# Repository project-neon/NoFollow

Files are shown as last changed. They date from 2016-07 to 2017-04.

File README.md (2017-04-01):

# NoFollow
The Software of NoBox's Line Follow robot of 2016
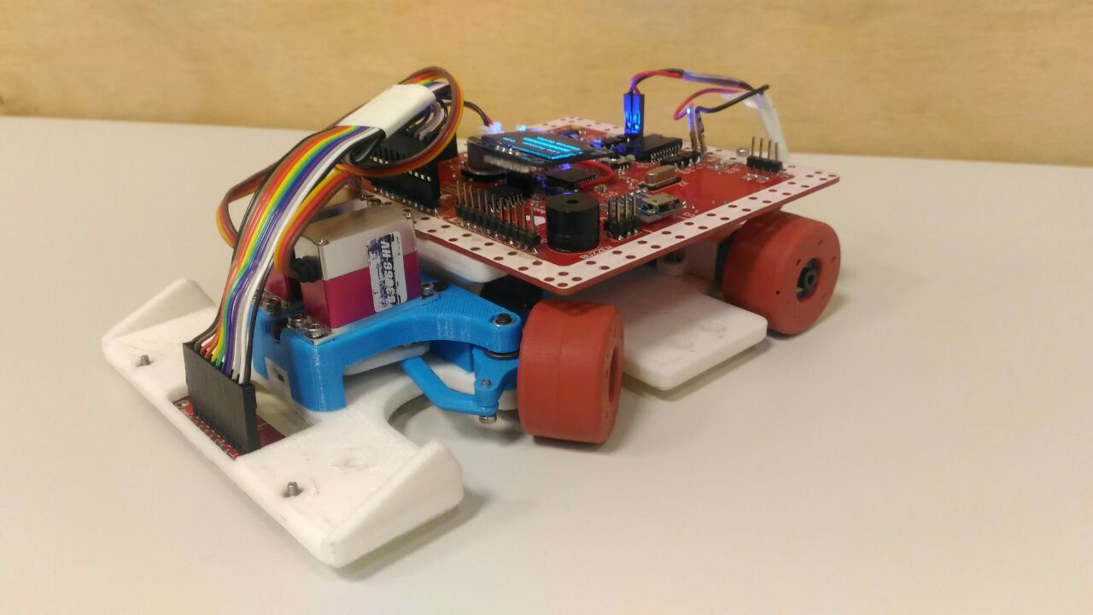
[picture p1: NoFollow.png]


<p align="center";> <b>NoFollow Final Version</b> </p>

# Parts of the puzzle

* `Firmware`: Is the main firmware that controls all the functions of the robot.
* `Eletric`: This keeps all the information about the electronics for the line following robot ‘NoFollow’.
* `Mechanic`: Contains the STL files of the robot design.

# Parts of the `Firmware` puzzle

* `activities`: Controls the robots motor power, threads callbacks and PID constants.

* `interface`: Show in the LED interface the time to stop the robot and read the comands by a joystick.

* `lineReader`: Read the outside sensors and check the conditions.

* `motors`: Initiates the "pinMODEs", sets power and directions of the motors.

* `pid`: Configures PID control on the angular
velocity of the robot.

* `robot`: Configurates the correct pinMODEs and beeps, defines the current robot's state.

* `runner`: Is the "menu" of the robot. In the interface receive the comands by the joystick to do tests actuators, calibrate steering and follow line.

# Contributors
* [Gustavo Silva de Paula](https://github.com/Gustavo-dPaula)
* [Ivan Seidel](http://github.com/ivanseidel)
* [João Pedro Poloni Ponce](https://github.com/JoaoPedroPP)
* [Lucas Andrade Cioffi](https://github.com/lacioffi)
* [Marcelo Farias](https://github.com/MarceloFariaz)
* [Yves-Medhard Tibe-Bi](https://github.com/yvesmedhard)

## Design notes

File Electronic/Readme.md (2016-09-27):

# NoFollow - Electronics



## CircuitMakerProject link <a href="https://workspace.circuitmaker.com/Projects/Details/Marcelo-Farias/NoFollowBoard">here</a>

## General Stuff

This repository keeps all the information about the electronics for the line following robot ‘NoFollow’.

THE MOST IMPORTANT ADVICE YOU CAN EVER GET ABOUT USING CIRCUITMAKER IS:
DONT. TRUST. DATABASE. COMPONENTS.

We did. It was not good.
Many of them are wrong - be it wrong sizes, wrong pins in the wrong places, wrong names, whatever! Don’t EVER 
trust them! Never! If possible, make them yourself! We had TONS of troubles because of this!

Anyway, proceeding:

To control the robot, we chose the Atmega 32U4 microcontroler (the same one that arduino Leonardo uses). 

However, this choice proved inadequate, since it’s memory was too small and couldn’t fit the entire intended 

program. We had to scrap the IMU because it’s library was too heavy and the LCD library had to suffer some
modifications to fit.

Here are the project sheets:

## Project Sheets

### `Main Sheet`:

Main Sheet

  This sheet just links all the other sheets together. The idea is that the 'Core' part does all the processing while
the other sheets worry about interfacing or power-related stuff.

### `Core Sheet`: 

Core Sheet

  In the core sheet we have the microcontroller and the necessary components to make it work properly - like a 
crystal oscillator and some capacitors. It also contains the usb header and its basic circuit.
The reset button is also included.

### `Power Sheet`:

Power Sheet

  This is the power sheet, and is filled with (duh) power related stuff.
This robot was designed to work with a battery of 7.4V which was connected to a voltage regulator LM1117 to 
supply 5V continuous. It has a contact to keep the circuit safe when turning on and off.

### `Sensor Sheet`:

Sensor Sheet

  We tried to put all the input/output devices in this sheet.
To detect the line on the ground we chose two analog arrays of eight infrared sensors, one overlapping the
other. Since the ATmega32U4 doesn't have 16 analog I/O’s, we had to use a mutiplex to access all 16 inputs
through only one pin.
  However, due in part to the small size of the Atmega’s memory and due in part to last-minute assembly, we only 
used one sensor. The robot worked anyway, but we don’t know if it would have worked better with two of them.
  Note about the MUX: we incorrectly used a big package, but there are smaller ones (and easier to find!) if you 
want to. We would have used them, but again: don’t trust database components.
  The capacitors are necessary for filtering the IMU (whatever that means).
  The LED_ON gate is connected directly to the ATMEGA, so as to turn off the LEDs when not in use and preserve 
battery. In hindsight, this was mostly useless.
  The buzzer was never used due to the memory shortage problem already cited.
  The button worked okay like this BUT it was placed wrongly on the circuit board. It was placed in a 45º angle, 
but the button works with a 90º axis so, for example, UP became UP-RIGHT and LEFT became UP-LEFT, and so forth. 
Like a compass turned 45 degrees to the right, you get it?

### `Comunications Sheet`:

Comunications Sheet

  This sheet was supposed to be for all communications - which eventually turned out to be just a bluetooth 
module.
  HC05 is a simple bluetooth module that worked fine. The small circuit on its left is a thingy that steps the 
voltage up and down so the HC05 doesn’t burn the Atmega and vice-versa. It’s very important.

### `Motor Sheet`:
Motor Sheet

  This is the sheet where all motors and things-that-go-spinning went.
There is an H-bridge for motor control, complete with all the stuff it needs to work, and the motors all have 
diodes to prevent dangerous reverse currents. 
  There are also LED’s that indicate if the motor is going forwards or backwards. These were just for debugging, 
so they aren’t necessary, but they honestly look pretty cool. I recommend them.
IMPORTANT: while routing, we used small copper lines to connect the motors to the H-bridge. We later fixed it, 
which was very good, because or else we would have the first ever line-burning robot.
  However, the H-bridge has a big metal plate underneath it to use as ground/heatsink. So don’t repeat our
mistake and don’t put routes underneath the H-bridge. We had to cut out some isolant tape and glue it on the 
H-bridge, which worked, but you can do better than that.

## Routed Board
Routed Board

This is the final routed board. Notice the huge ground lines - these are important, since the motors are going 
to draw a LOT of current. 
  IMPORTANT: the LCD display is routed incorrectly. This was a CircuitMaker bug which (apparently) didn’t save a 
fix we made to the LCD part and ended up carrying a wrongly-pinned LCD to the routing process and, basically, 
gave us trouble.

## About soldering:
Please, PLEASE check if your PCB manufacturing company can make metallized vias. To our surprise, ours didn’t, 
which meant we had to solder 200+ metal bits to make them work, and it was generally unpleasant and caused us a 
lot of headache.

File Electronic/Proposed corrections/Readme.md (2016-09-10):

# Proposed corrections

This folder contains the (semi)fixed project.
We fixed the errors on CircuitMaker and exported the project again.
This was partly educational and partly so you can use it without the headaches we had.
Let's get on to it:

##WHAT WAS FIXED:

###MUX size:
The MUX was inverted and the package used was unecesseraly big. This was fixed.

###LCD pins:
LCD pins were not properly connected. Now they are.

###ATMEGA pins:
MC pins were reallocated to simplify stuff and make stuff prettier and stuff.
New positions are available in the sheet.

###Button:
Button was rotated because it was wrong before.

###L298 Ground:
Now the L298 is properly grounded. Heat dissipation is better this way.

###Servos:
Servos are now connected directly to the battery. That's how they were supposed to be.

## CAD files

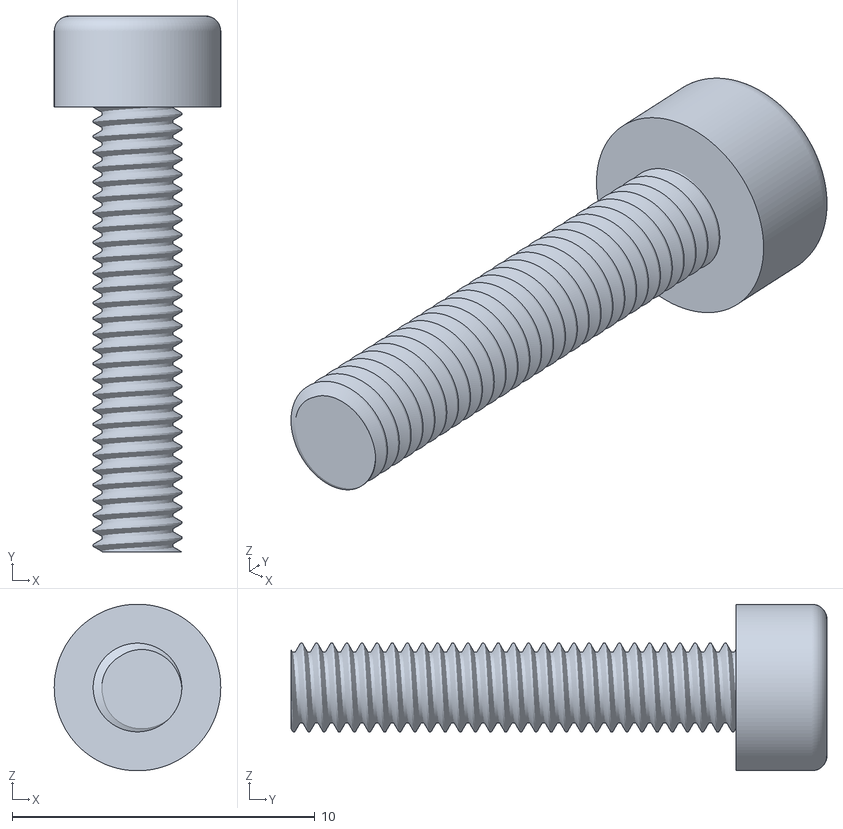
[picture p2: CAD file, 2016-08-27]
Mechanics/STLFiles/Allen_M3x18.stl
5.50 x 17.7 x 5.50

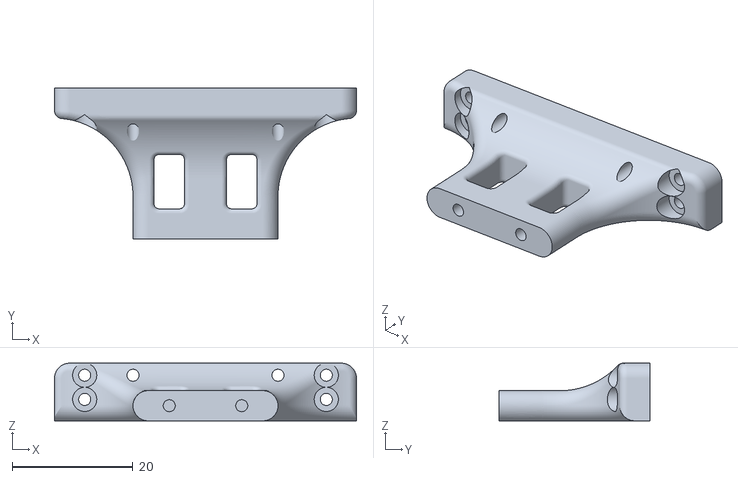
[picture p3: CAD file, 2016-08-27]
Mechanics/STLFiles/Support_Board.stl
50.0 x 25.0 x 9.55

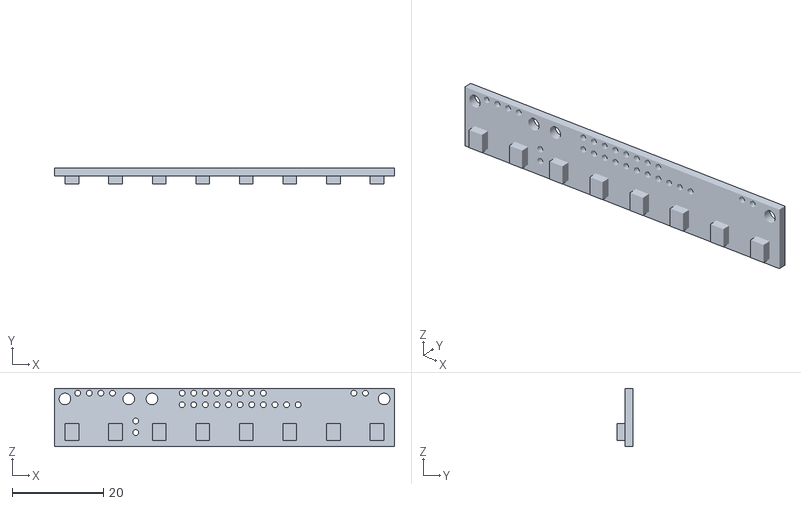
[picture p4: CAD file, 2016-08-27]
Mechanics/STLFiles/QTR-8RC.stl
74.4 x 3.48 x 12.7

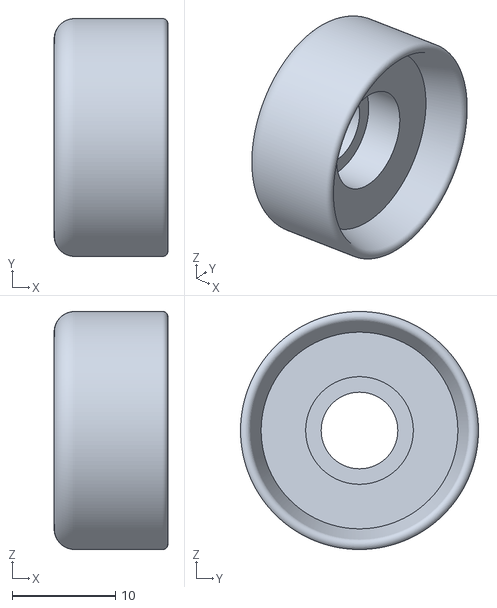
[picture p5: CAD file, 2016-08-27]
Mechanics/STLFiles/Wheel.stl
11.0 x 23.0 x 23.0

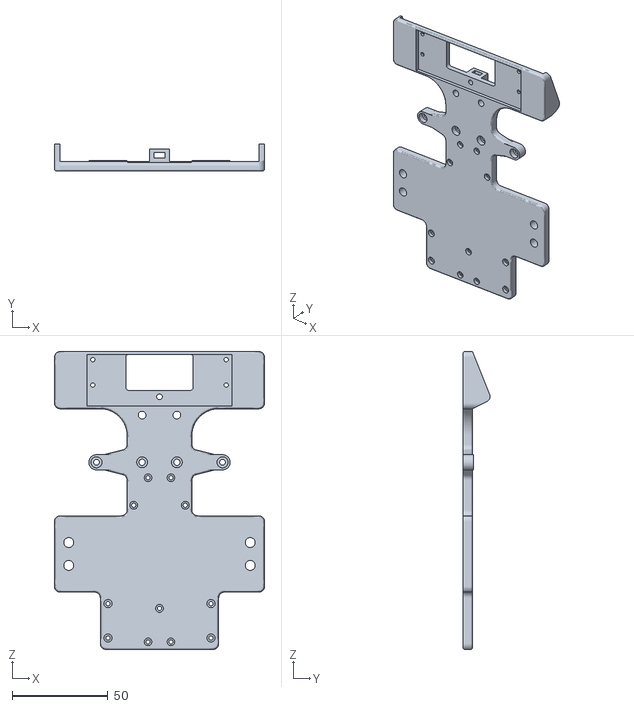
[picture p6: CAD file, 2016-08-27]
Mechanics/STLFiles/Base.stl
110.0 x 14.2 x 156.0

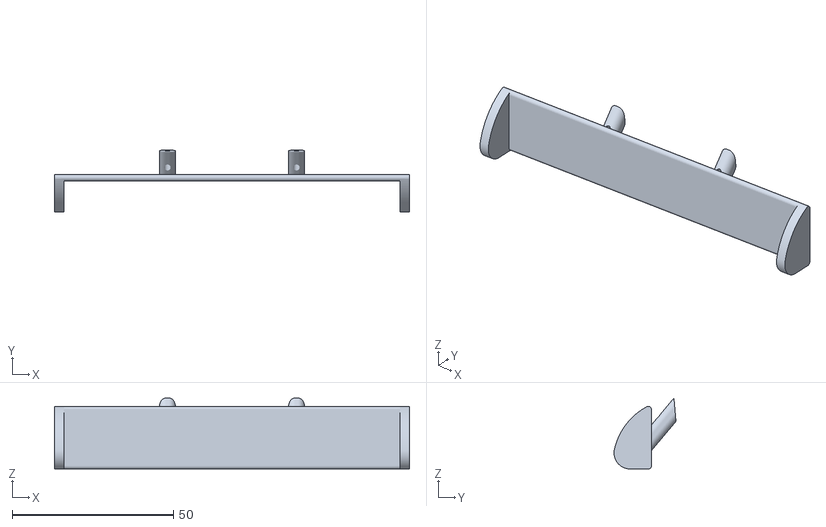
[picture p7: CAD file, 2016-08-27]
Mechanics/STLFiles/Spoiler.stl
110.0 x 19.2 x 22.0

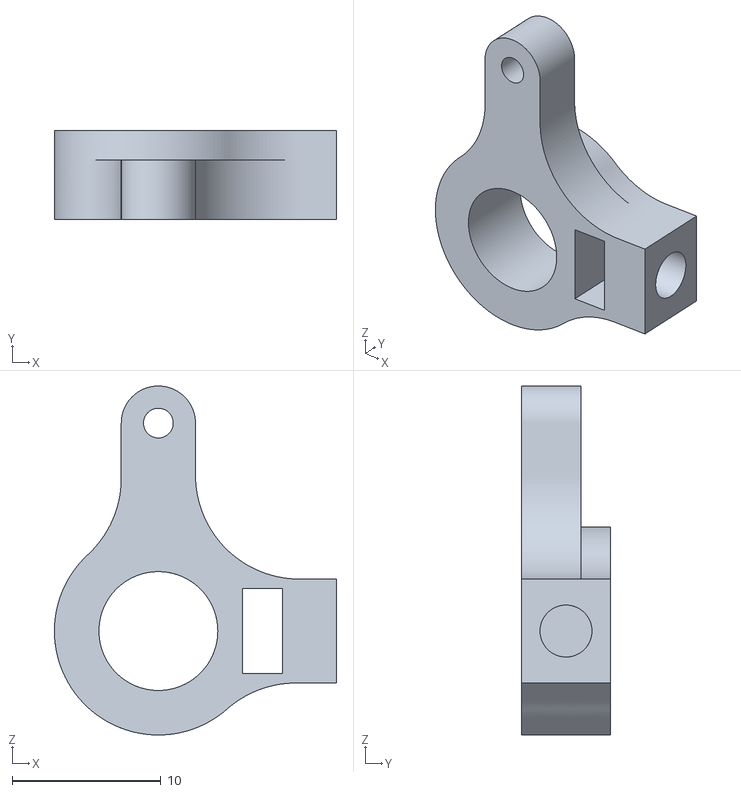
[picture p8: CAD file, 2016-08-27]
Mechanics/STLFiles/Direction_Bearing_Ring_Left.stl
19.0 x 6.00 x 23.5

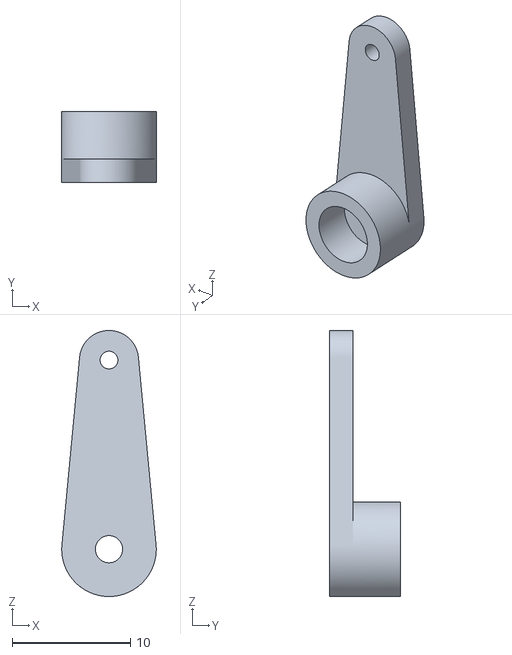
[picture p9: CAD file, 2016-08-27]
Mechanics/STLFiles/Servo_Arm.stl
8.00 x 6.00 x 22.5

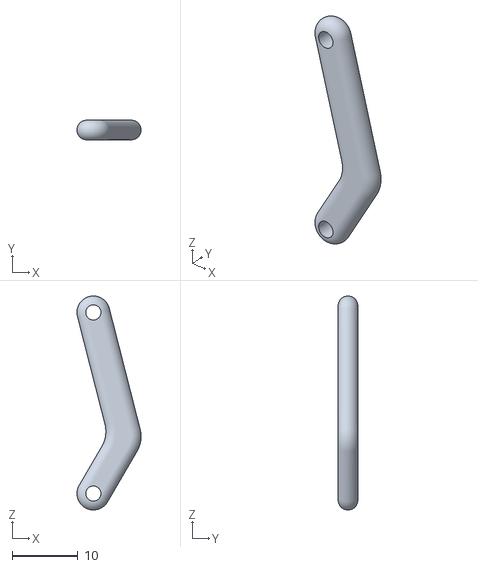
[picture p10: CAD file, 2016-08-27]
Mechanics/STLFiles/Direction_Bar_Right.stl
9.74 x 3.00 x 32.5

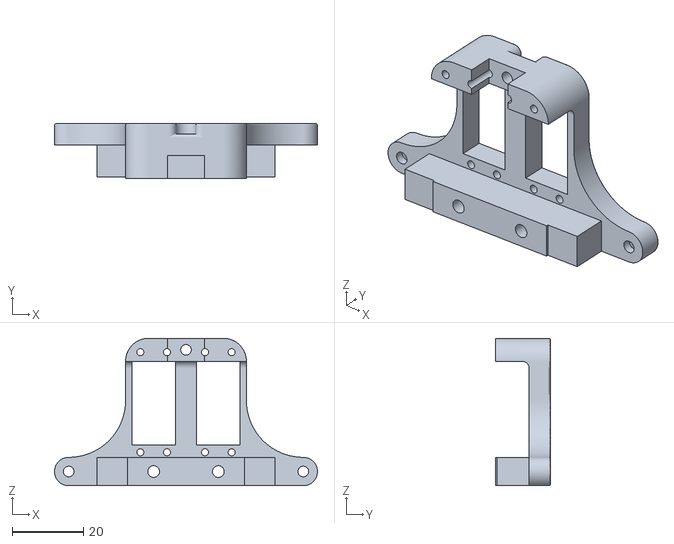
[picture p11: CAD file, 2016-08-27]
Mechanics/STLFiles/Fixer_Direction.stl
74.0 x 15.5 x 41.5

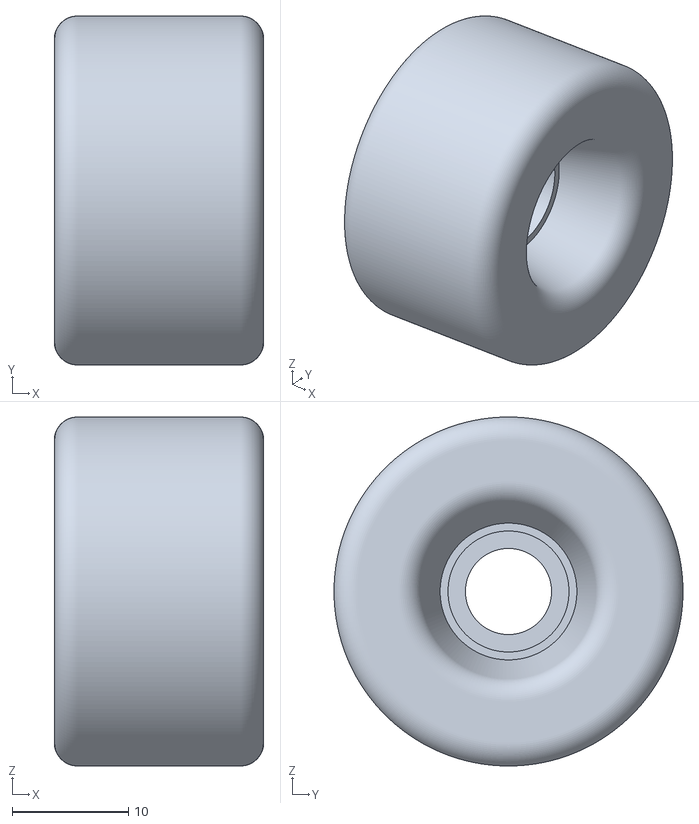
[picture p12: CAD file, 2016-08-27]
Mechanics/STLFiles/Wheel_With_Tire.stl
18.0 x 30.0 x 30.0

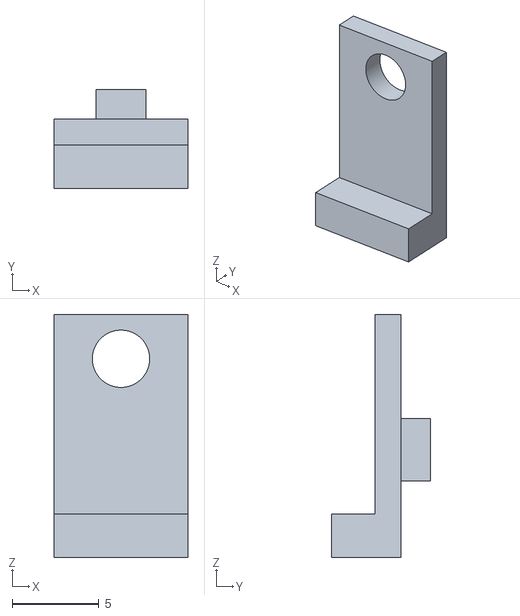
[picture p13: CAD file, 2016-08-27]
Mechanics/STLFiles/QTR-1A.stl
7.70 x 5.70 x 14.0

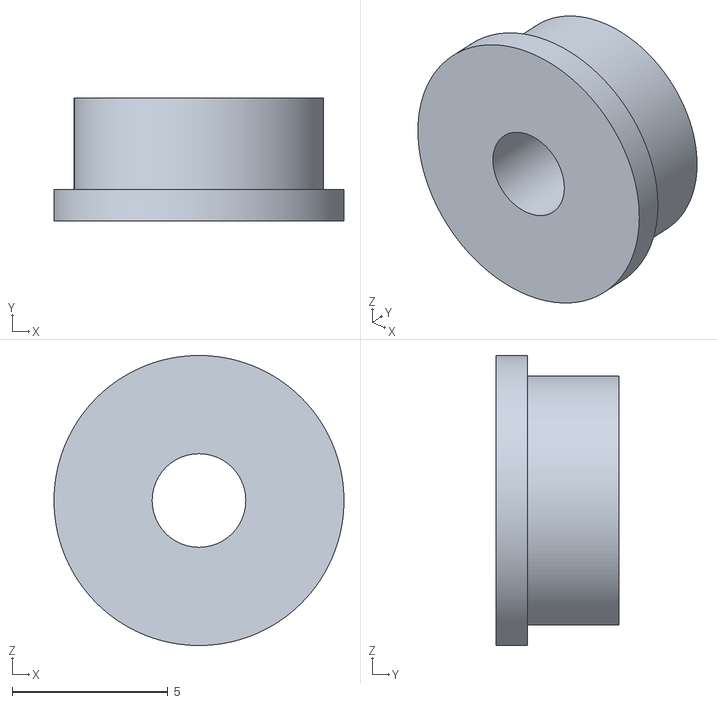
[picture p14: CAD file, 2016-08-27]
Mechanics/STLFiles/Bearing_3x3x8 .stl
9.30 x 3.94 x 9.30

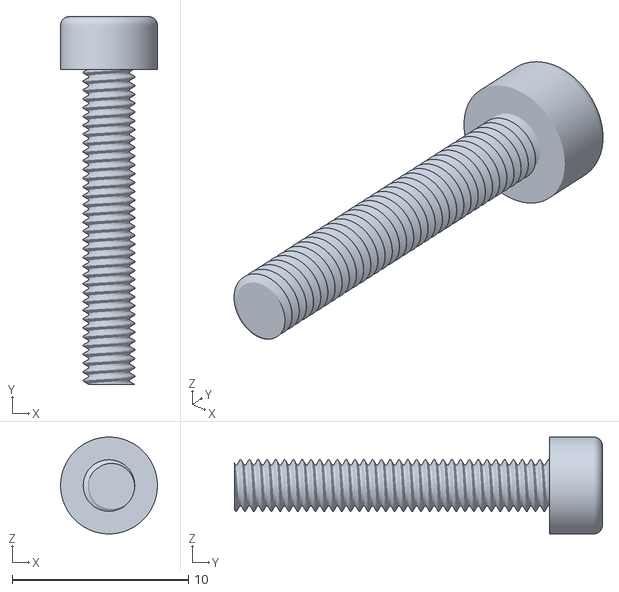
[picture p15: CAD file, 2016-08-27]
Mechanics/STLFiles/Allen_M3x21.stl
5.50 x 20.9 x 5.50

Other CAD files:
Mechanics/STLFiles/Direction_Bearing_Ring_Right.stl
Mechanics/STLFiles/Battery_Support.stl
Mechanics/STLFiles/Sensor_Arm.stl
Mechanics/STLFiles/Direction_Bar_Left.stl
Mechanics/STLFiles/Allen_M2x10.stl
Mechanics/STLFiles/Allen_M3x10.stl
Mechanics/STLFiles/Micro_Gear_Motor_Extended_30-1_With_Bracket.stl
Mechanics/STLFiles/Nut_M2x1.5x4.stl
Mechanics/STLFiles/Nut_M3x4x5.5 (Autolock).stl
Mechanics/STLFiles/Nut_M3x4x5.5.stl
Mechanics/STLFiles/Rear_Wheel_Cube.stl
Mechanics/STLFiles/ServoTGY-306GV2.2.stl
Mechanics/STLFiles/Washer_7x3.3x0.5.stl
Mechanics/STLFiles/Zippy_Lipo_1300mAh.stl

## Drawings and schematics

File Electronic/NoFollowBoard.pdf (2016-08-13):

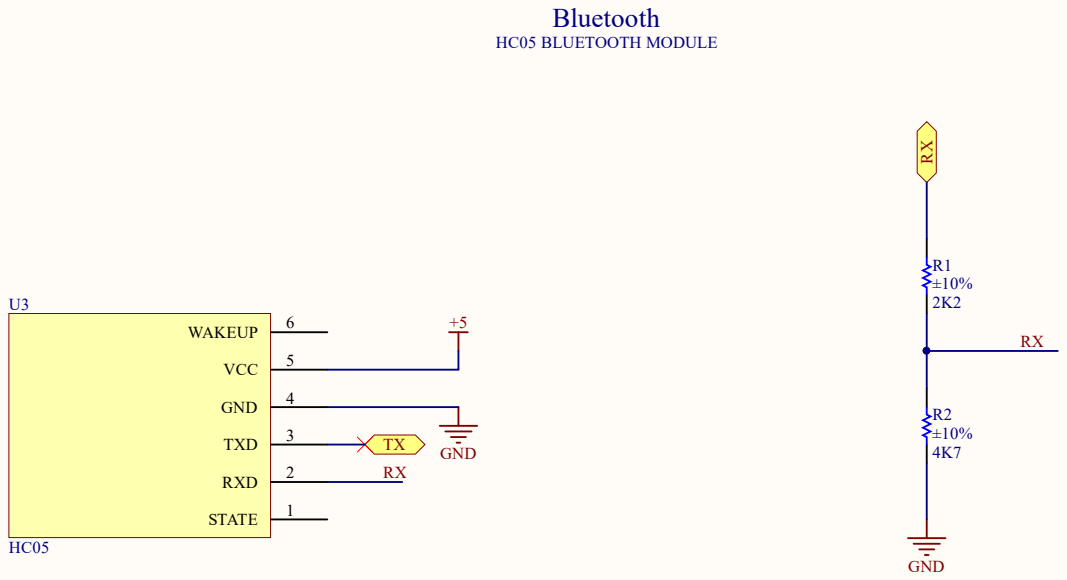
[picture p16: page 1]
5 BLUETOOTH MODULE

Size A | Nu m ber | Revisio n

Date: 1/0 7/2 6 | Sheet o f
File: C o m m u nicatio n.SchDo c | Drawn B y :

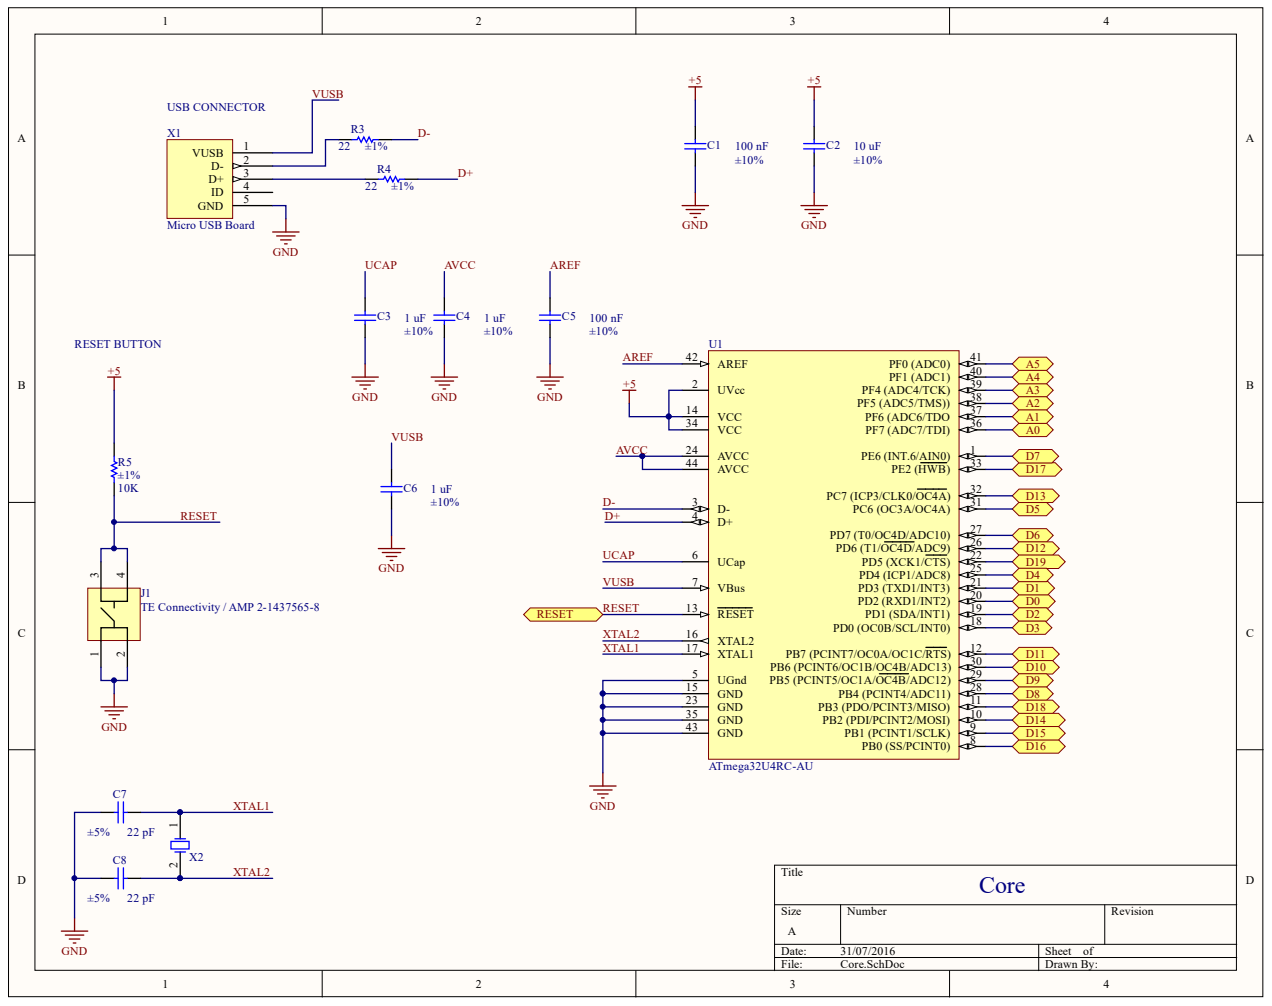
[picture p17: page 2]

1 4

1 5
2 3

Size | Nu m ber | Revisio n

Date: 1/0 7/2 6 | Sheet o f
File: C o re.SchDo c | Drawn B y :

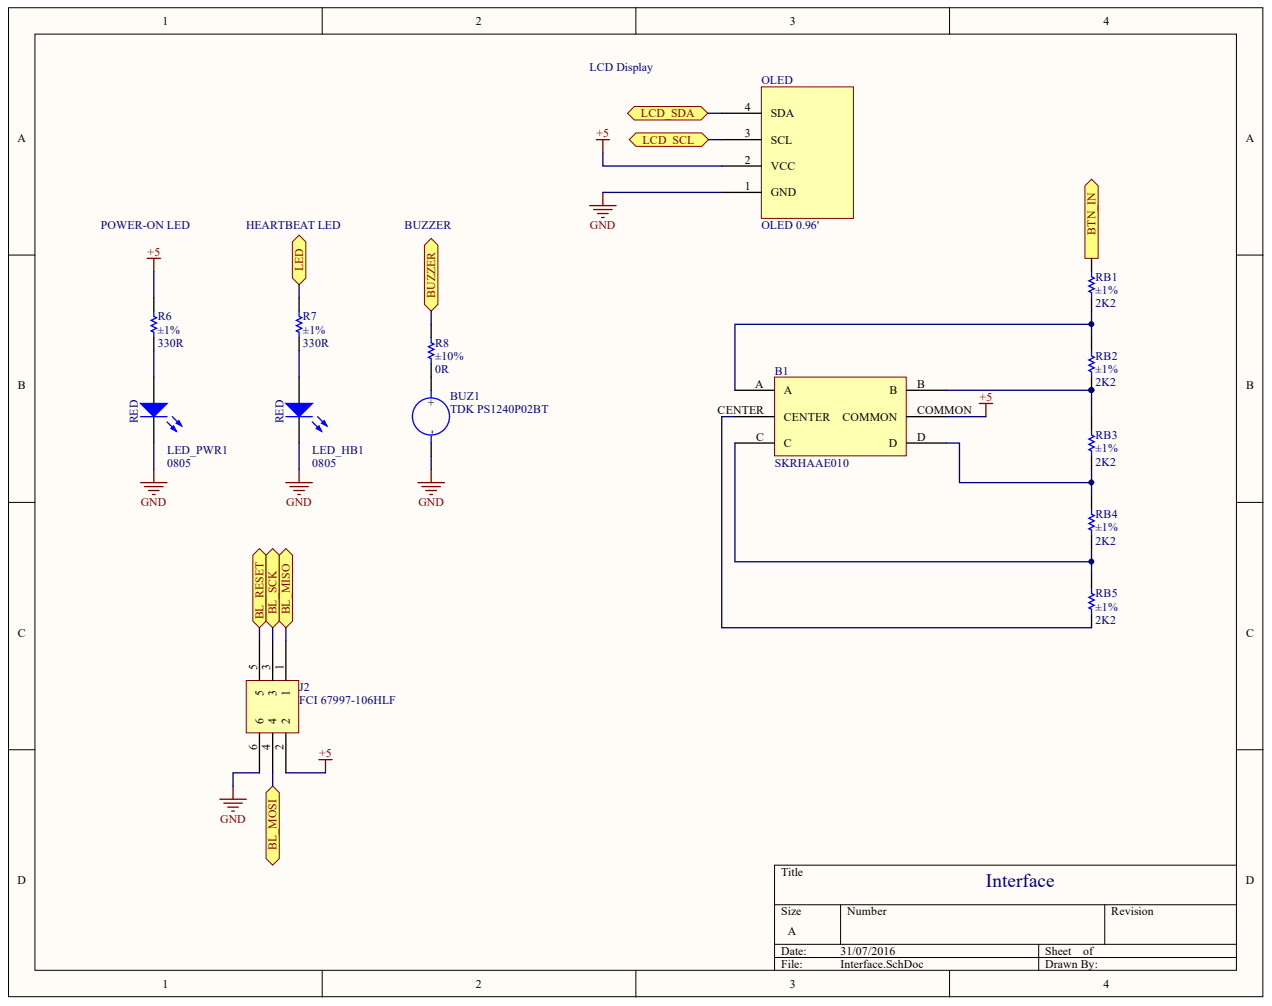
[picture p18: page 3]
GND; GND LED; BUZZER; LCD Display; -ON LED; HEARTBEAT LED; OLED 0.9; TDK PS1

Size | Nu m ber | Revisio n

Date: 1/0 7/2 6 | Sheet o f
File: I nter face.SchDo c | Drawn B y :

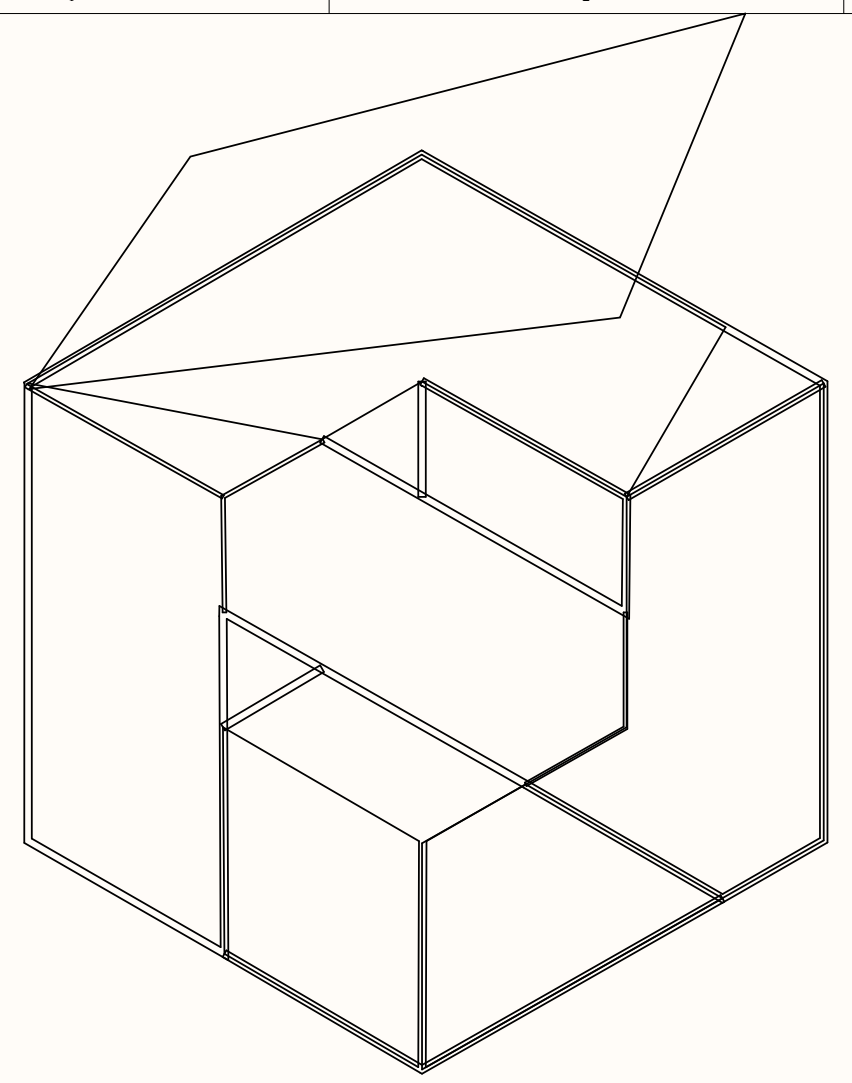
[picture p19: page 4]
Date:; Sheet of; File:; Logo-Linhas-Placa Circuito.SchDoc; Drawn By:

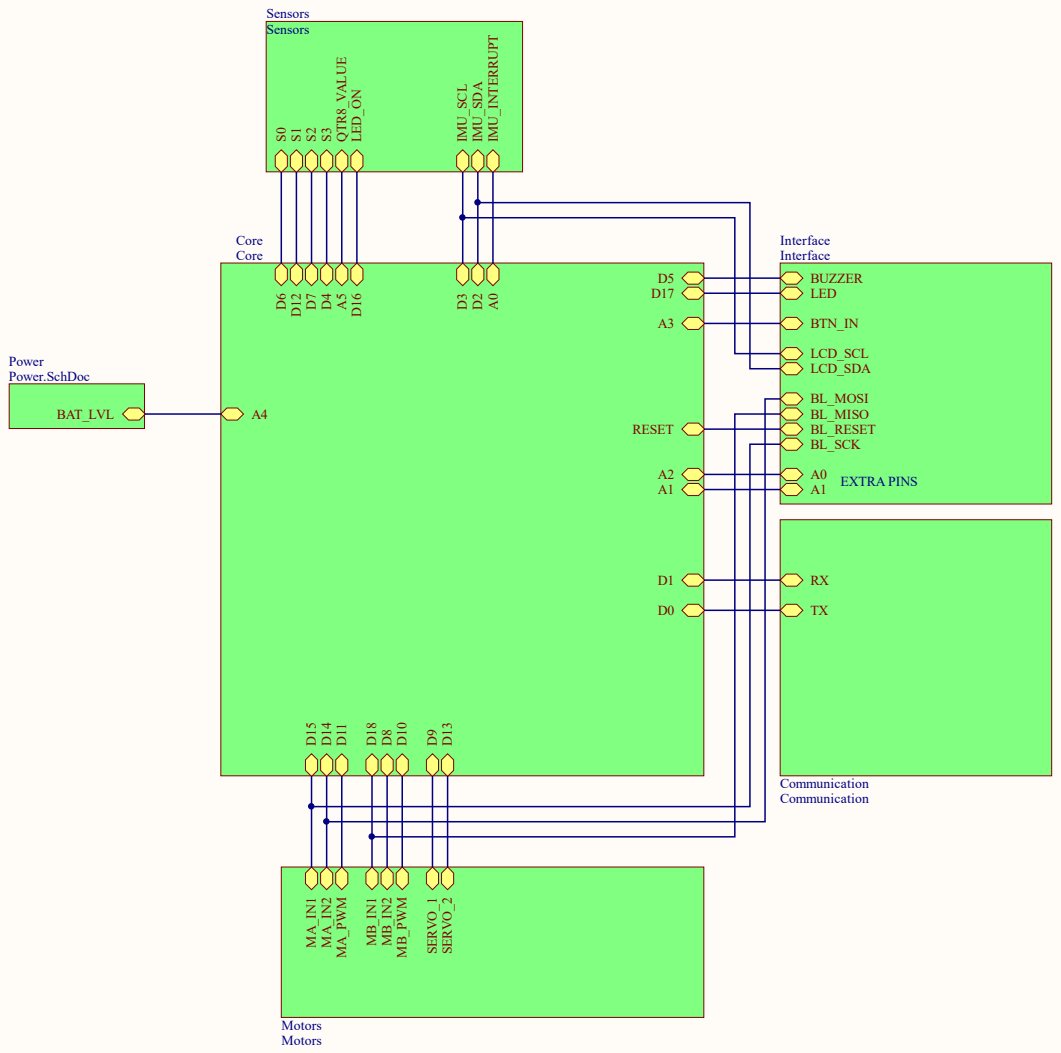
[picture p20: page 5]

RESET

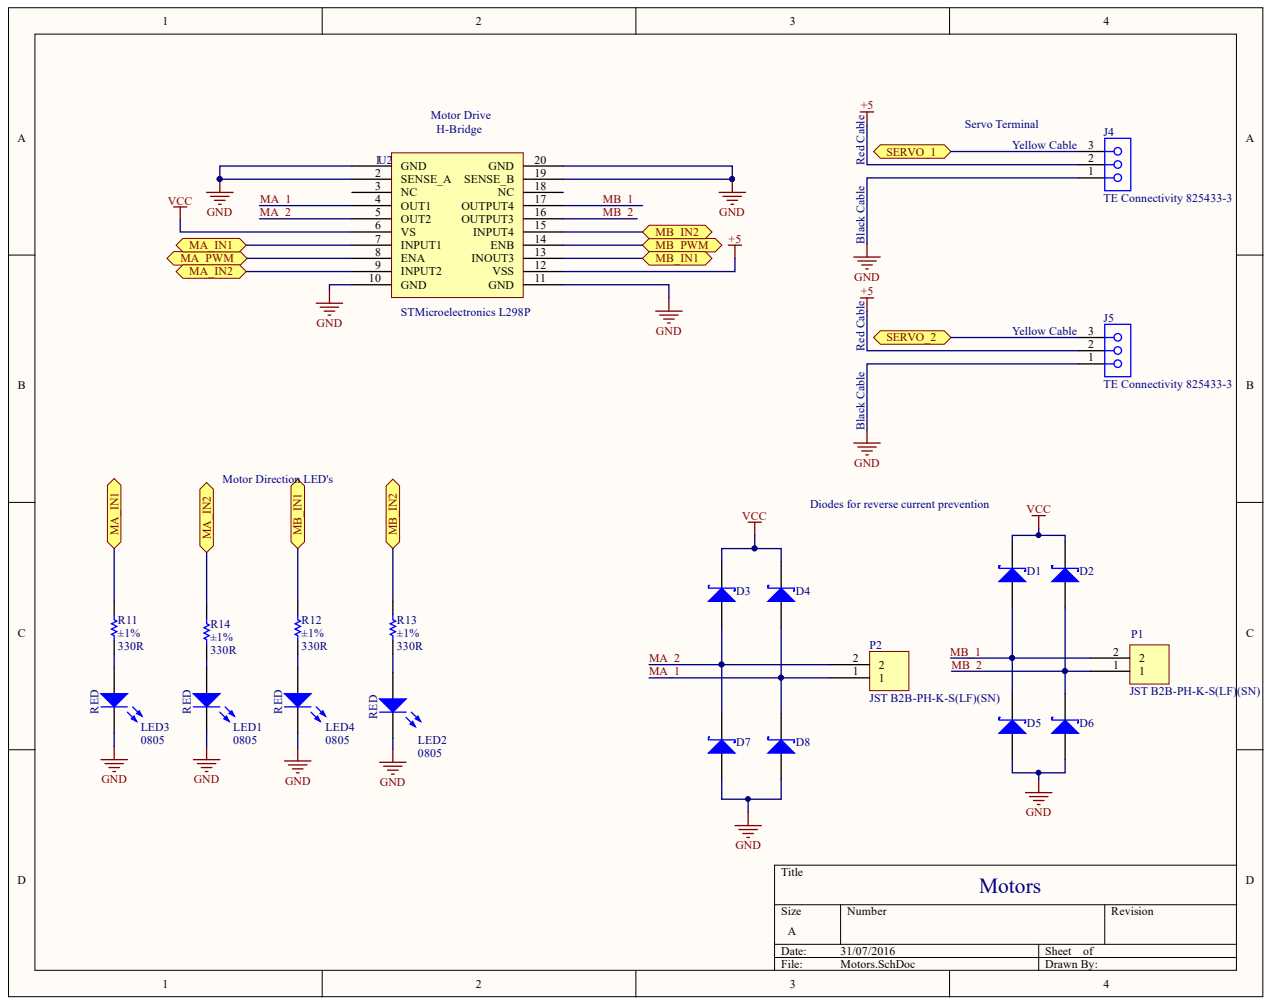
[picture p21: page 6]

Diodes for reverse current prevention

JST B2B-PH-K-S(LF)(SN)

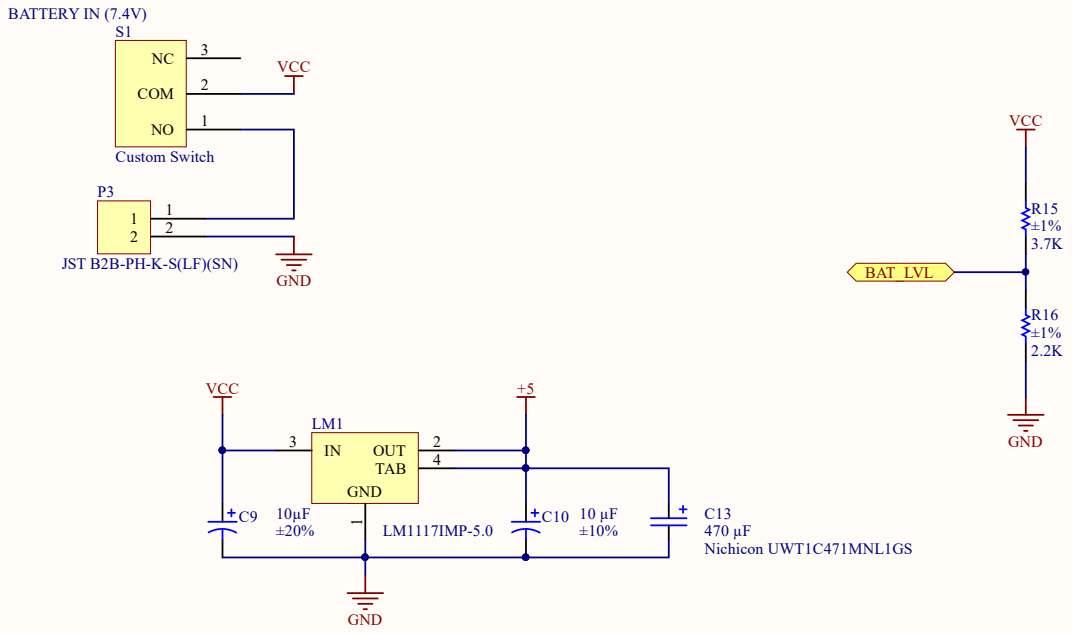
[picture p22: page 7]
File:; Power.SchDoc; Drawn By:; OUT; 1 TAB 4; BATTERY IN (7.4V); Custom Switch; 470 µF Nichicon UWT1C471MNL1GS

JST B2B-PH-K-S(LF)(SN)

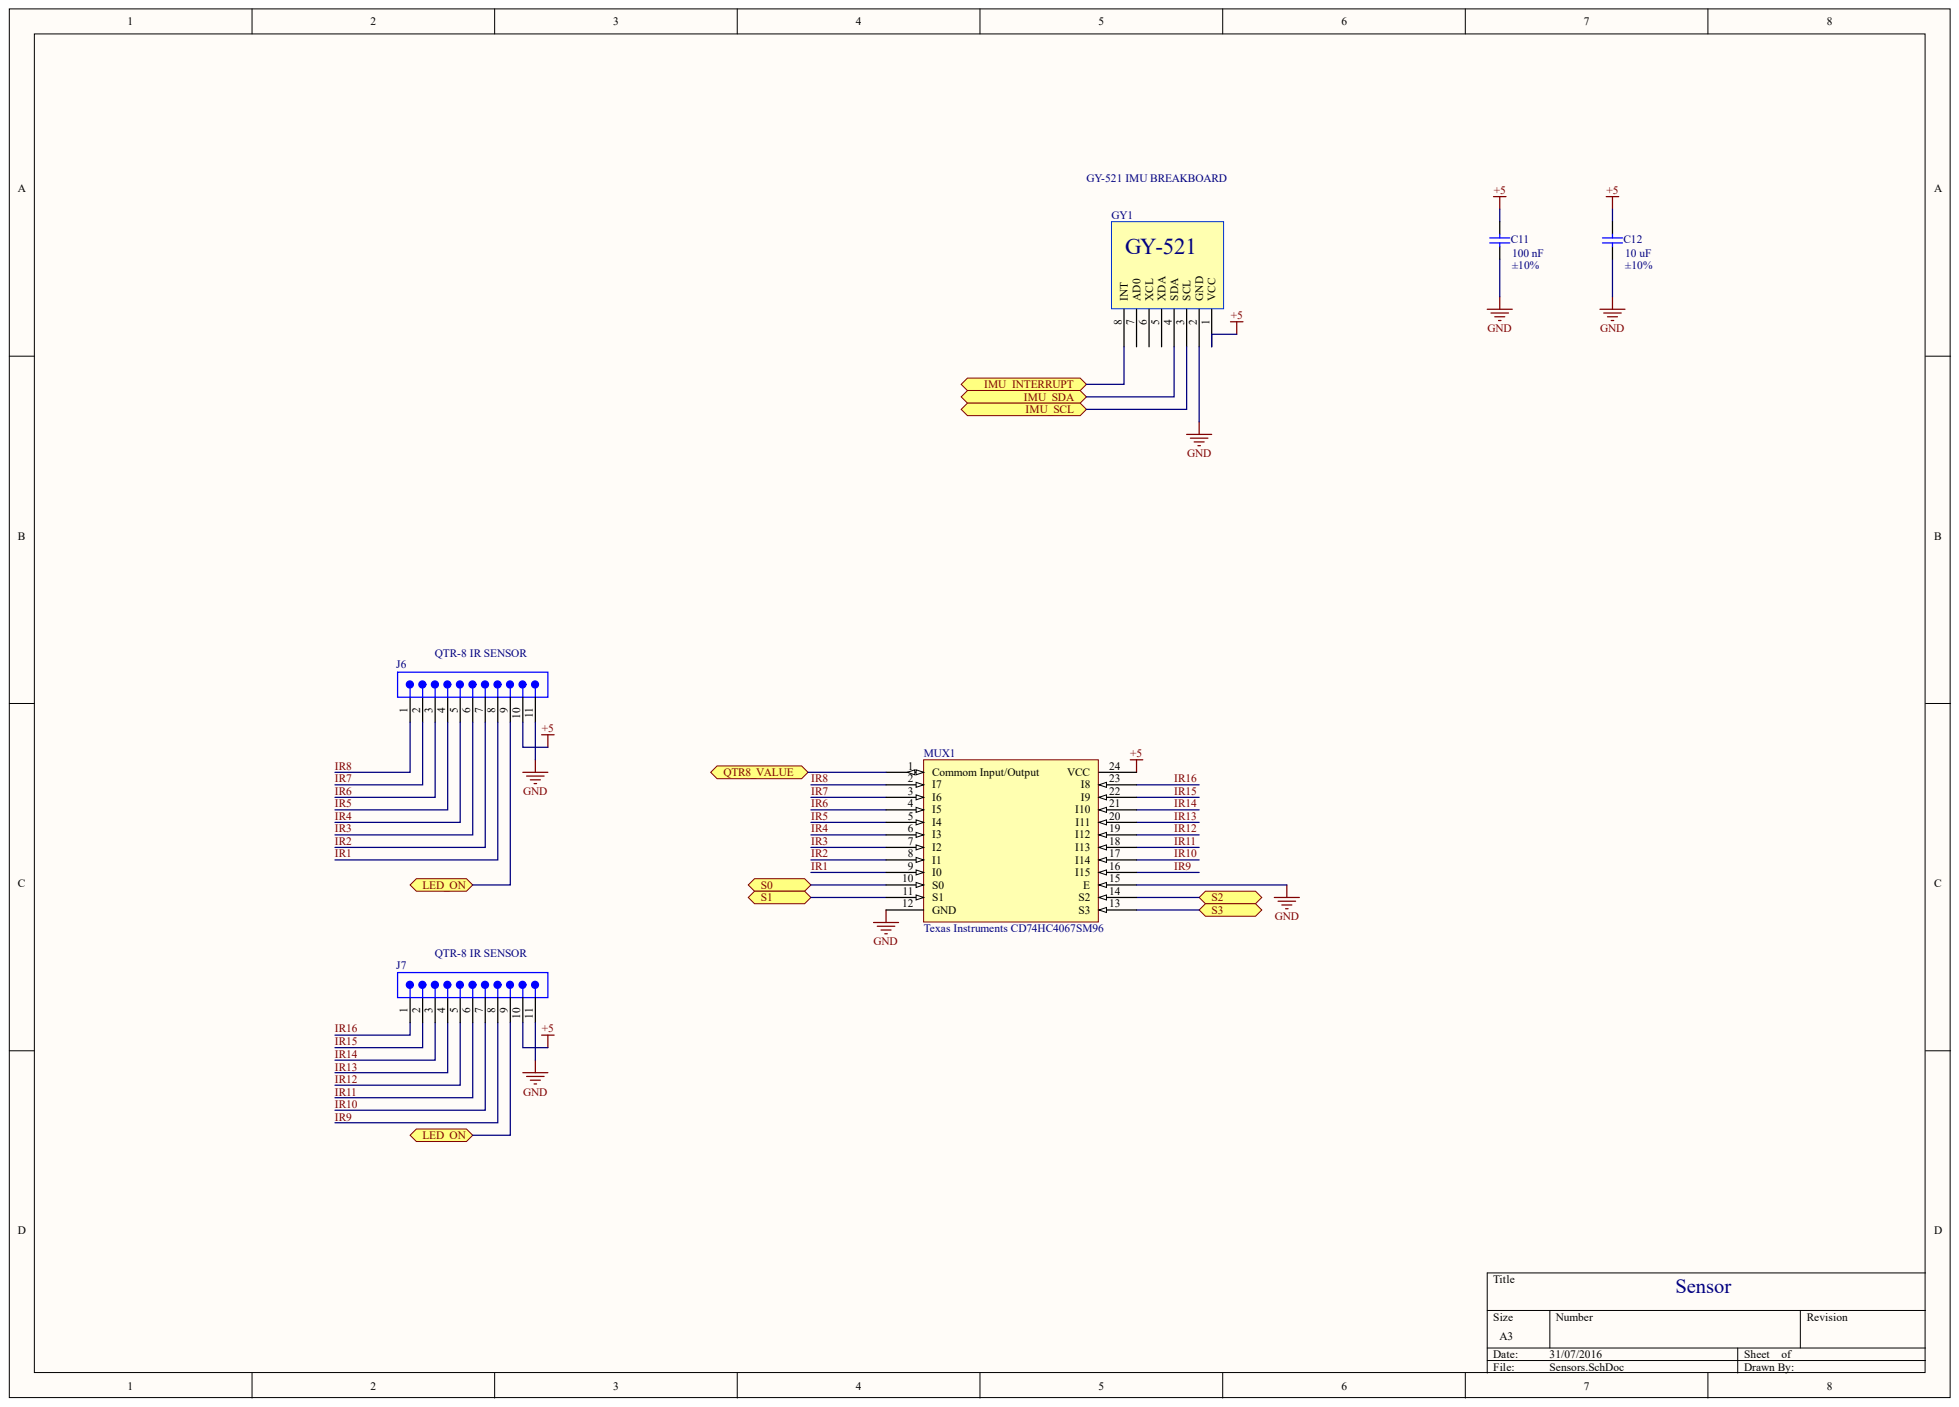
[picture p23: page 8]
File:; Sensors.SchDoc; Drawn By:; VCC; 24 Commom Input/Output 1; I7 2 I6 3 I5 4 I4 5 I3 6 I2 7 I1 8 I0 9 S0 10 S1 11 GND 12; Texas Instruments CD74HC4067SM96

GY-521 IMU BREAKBOARD

VCC 1 GND 2 SCL 3 SDA 4 XDA 5 XCL 6 AD0 7 INT 8 GY-521

QTR-8 IR SENSOR

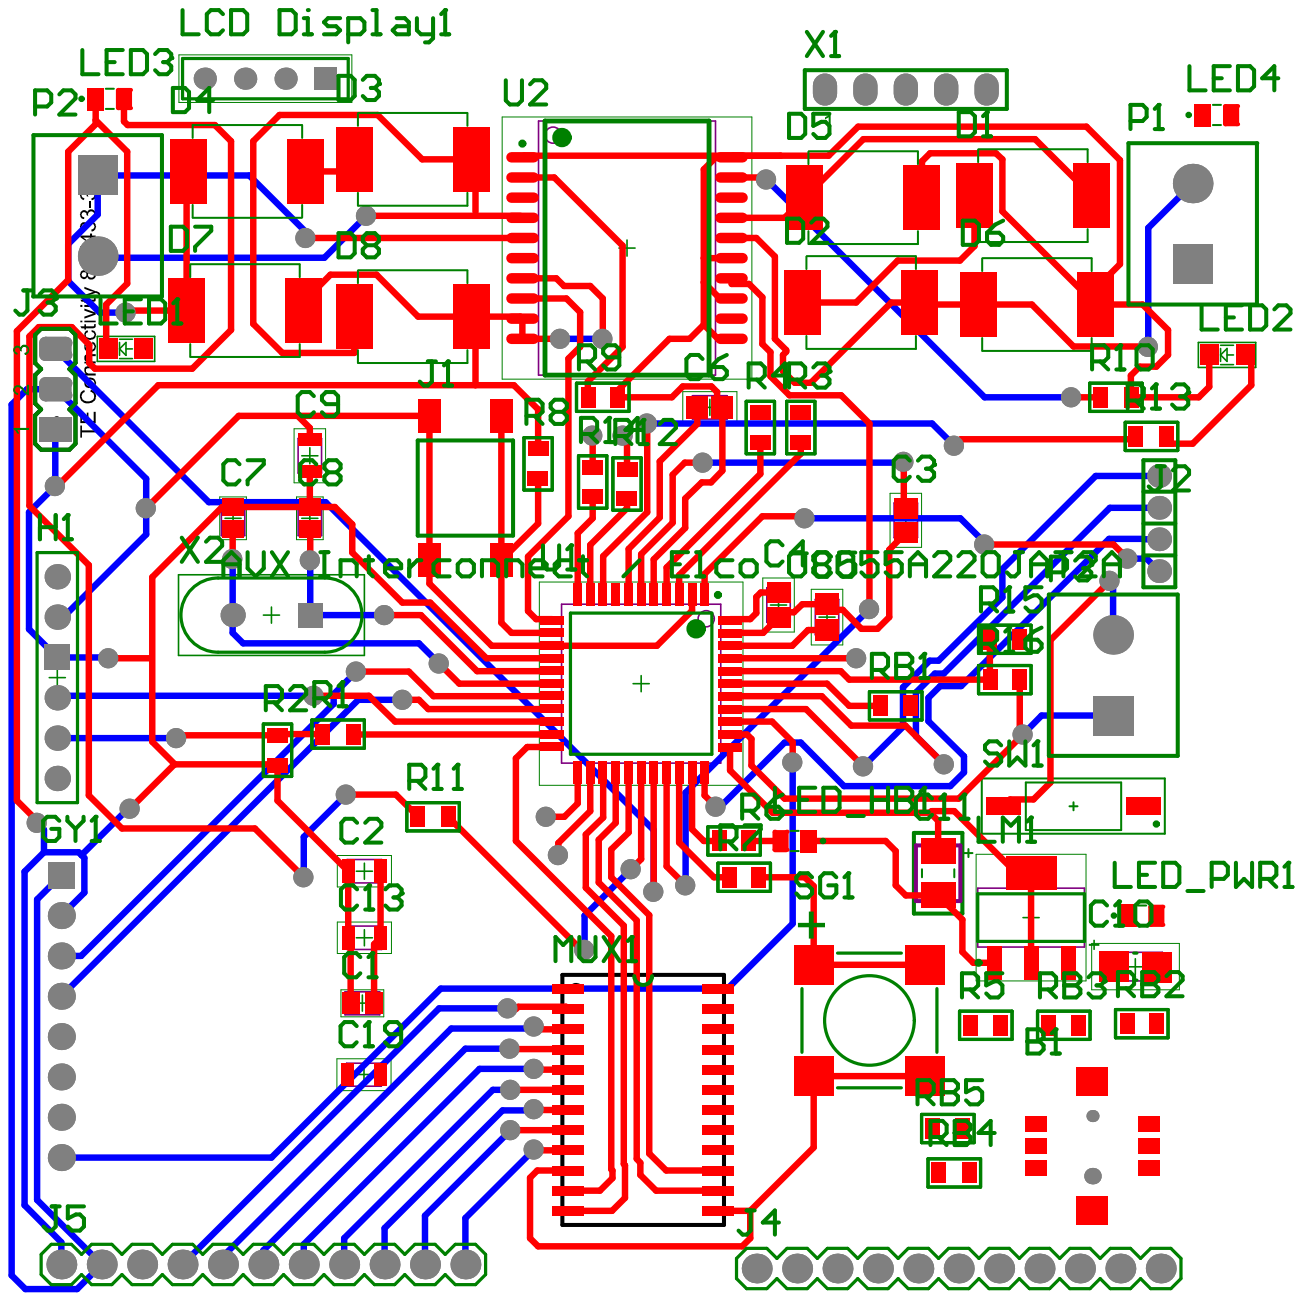
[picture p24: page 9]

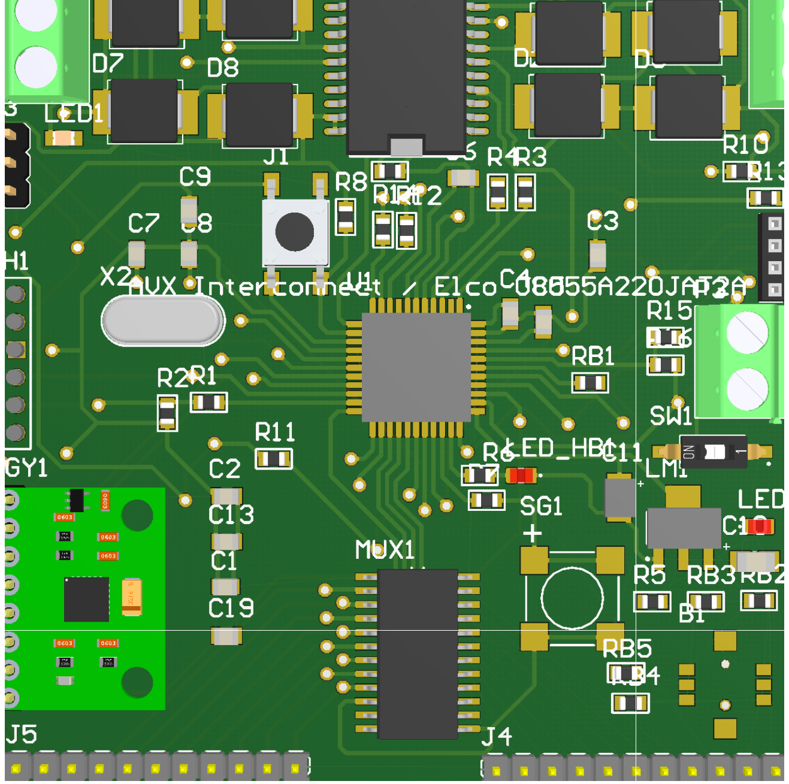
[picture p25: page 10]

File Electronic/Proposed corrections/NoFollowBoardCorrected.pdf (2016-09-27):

5 BLUETOOTH MODULE

Size A | Nu m ber | Revisio n

Date: 0/0 9/2 6 | Sheet o f
File: C o m m u nicatio n.SchDo c | Drawn B y :

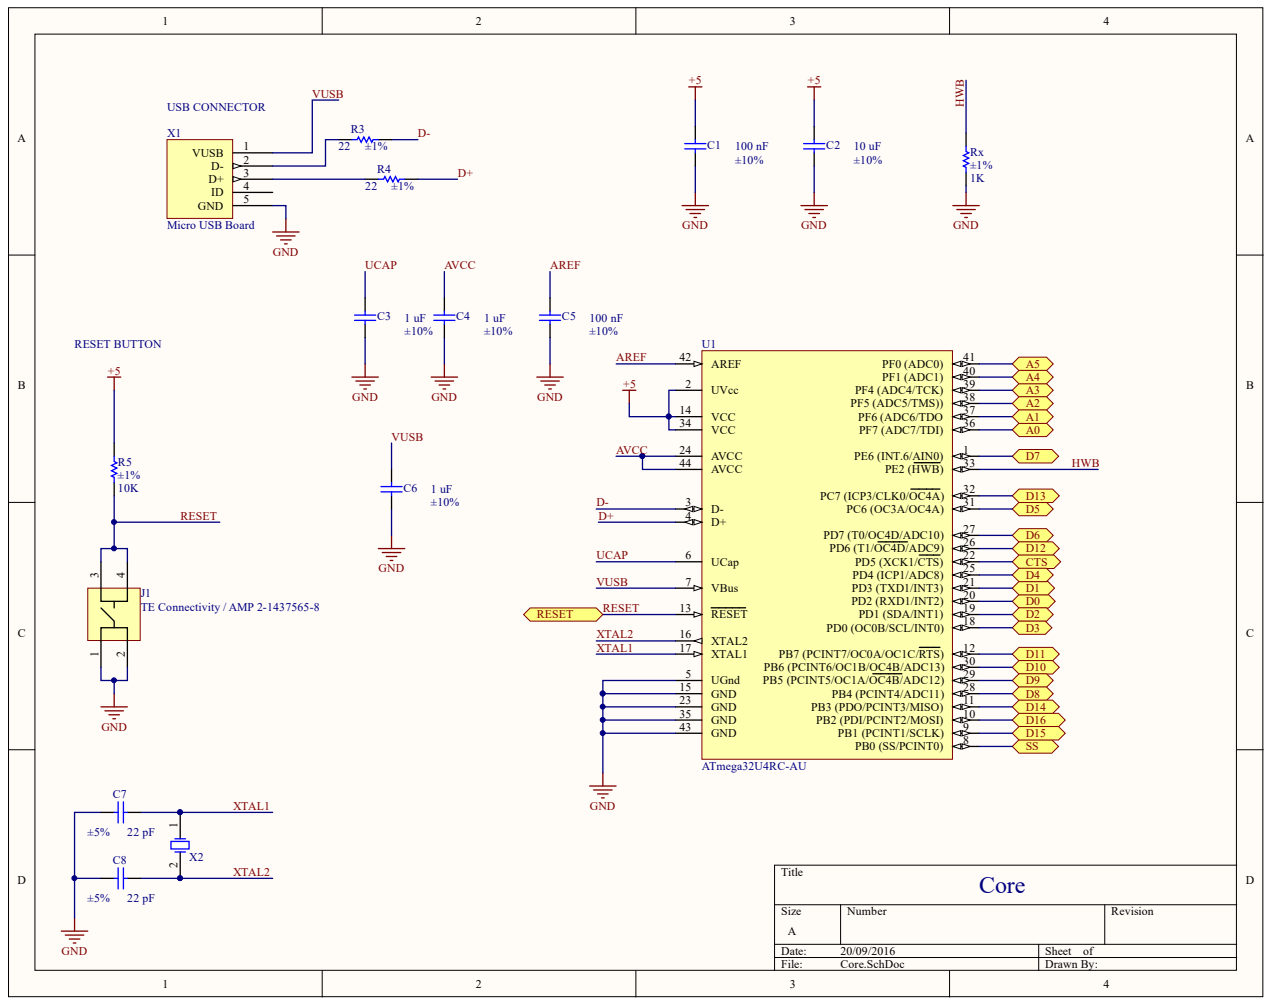
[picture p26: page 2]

Size | Number | Revision

Date: 20/09/2016 | Sheet of
File: Core.SchDoc | Drawn By:

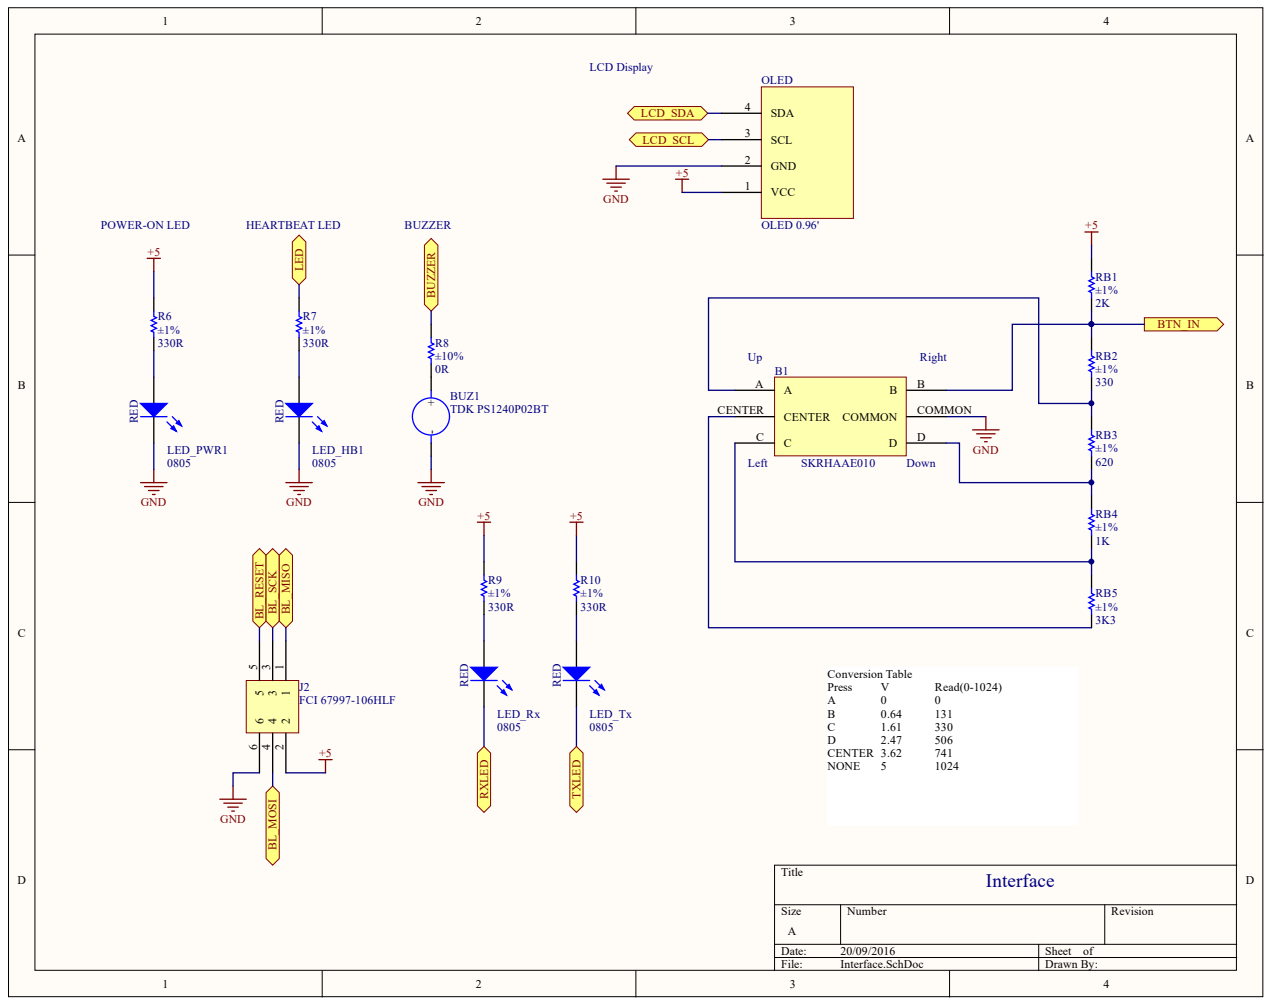
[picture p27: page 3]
File:; Interface.SchDoc; Drawn By:; LCD Display; POWER-ON LED; HEARTBEAT LED; BUZZER; FCI 67997-106HLF; CENTER CENTER; TDK PS1240P02BT; VCC 1; GND 2; SCL 3; SDA 4; OLED 0.96'; TXLED +5; Conversion Table; CENTER 3.62

File:; Logo-Linhas-Placa Circuito.SchDoc; Drawn By:


RESET

SS CTS D1 D0


Diodes for reverse current prevention

JST B2B-PH-K-S(LF)(SN)

File:; Power.SchDoc; Drawn By:; OUT; 1 TAB 4; BATTERY IN (7.4V); Custom Switch; 470 µF Nichicon UWT1C471MNL1GS

JST B2B-PH-K-S(LF)(SN)

File:; Sensors.SchDoc; Drawn By:; VCC; 24 Commom Input/Output 1; I7 2 I6 3 I5 4 I4 5 I3 6 I2 7 I1 8 I0 9 S0 10 S1 11 GND 12; Texas Instruments CD74HC4067

GY-521 IMU BREAKBOARD

VCC 1 GND 2 SCL 3 SDA 4 XDA 5 XCL 6 AD0 7 INT 8 GY-521

QTR-8 IR SENSOR



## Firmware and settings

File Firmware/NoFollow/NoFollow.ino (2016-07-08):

// this class will contain the mais code that's called by the robot
//It will initiate the diferents robot's functions in the propper and logical order
// System Includes

// External Libraries
// #include <SPI.h>
#include <I2Cdev.h>
#include <SPI.h>
#include <Wire.h>
#include <Servo.h>
#include <Thread.h>
#include <EEPROM.h>
#include <Adafruit_GFX.h>
#include <Adafruit_SSD1306.h>
// #include <RH_NRF24.h>
#include <ThreadController.h>
// #include <RHReliableDatagram.h>
#include <MPU6050_6Axis_MotionApps20.h>


// Custom Util
#include "_types.h"
#include "_config.h"

// Modules
// #include "imu.h"
#include "pid.h"
#include "robot.h"
#include "motors.h"
#include "runner.h"
#include "interface.h"
#include "lineReader.h"
#include "activities.h"
// #include "controller.h"


void setup(){

  // Initialize Robot state and I/O Pins
  Robot::init();

  // Initialize Attitude/Orientation module (initializes MPU6050 internally)
  // Attitude::init();

  // Initialize Interface Display/Buttons/Serial debug
  Interface::init();

  // Initalize Line Sensors
  LineReader::init();

  // Initalize Motors (object)
  Motors::init();

  // Initialize Runner (Manages program execution)
  Runner::init();

  // Initialize Motor controllers (with PID's)
  // Controller::init();

}

// long start, end;
int pos = 0;
void loop(){
  // if(Interface::readButton() == STICK_RIGHT){
  //   pos++;
  //   Motors::setSteering(pos);
  //   delay(50);
  // }
  //
  // if(Interface::readButton() == STICK_LEFT){
  //   pos--;
  //   Motors::setSteering(pos);
  //   delay(50);
  // }
  //
  // if(Interface::readButton() == STICK_CENTER){
  //   while(Interface::readButton() != STICK_RELEASED);
  //
  //   Motors::setPower(50, 50);
  //   delay(4000);
  //   Motors::setPower(0, 0);
  // }
  // static int foo;

  // start = micros();
  system.run();
  // end = micros();

  // if((++foo) % 10000 == 0)
    // LOG("loopt: "); LOG(end-start); LOG("\n");

}

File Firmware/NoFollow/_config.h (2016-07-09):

#include <stdint.h>
#include <math.h>

#ifndef CONFIG_H
#define CONFIG_H


//
// Project
//
#define PROJECT_NAME            F("LineFollowFirmware")
#define PROJECT_VERSION         F("v1.00")


//
// Interface (Buzzer/Leds)
//
#define PIN_BUZZER              10
#define PIN_JOYSTICK            A3


//
// Serial DEBUG
//
#define SERIAL_SPEED 						115200
#define LOG 								    Serial.print


//
// Mux Settings
//
#define PIN_MUX_ENABLE          16
#define PIN_MUX_AN              A5
#define PIN_MUX_S0              6
#define PIN_MUX_S1              A1
#define PIN_MUX_S2              7
#define PIN_MUX_S3              4

//
// Stick Settings
//
#define STICK_RELEASED          254
#define STICK_UP                17
#define STICK_LEFT              3
#define STICK_DOWN              42
#define STICK_RIGHT             30
#define STICK_CENTER            52

//
// EEPROM Adresses
//
#define EEPROM_ADR_SENSOR_MIN   0x01
#define EEPROM_ADR_SENSOR_MAX   0x02
#define EEPROM_STEER_PHASE      0x03
#define EEPROM_STEER_CONVERGE   0x04


//
// I2C Config (IMU/Display
//
#define DISPLAY_ADDRESS         0x3C
#define IMU_INTERRUPT_CHANNEL   0

//
// Motors config (H-Bridge)
//
#define MOTOR_ABS_MAX           255
#define PIN_M1_EN               11
#define PIN_M1_IN1              MOSI
#define PIN_M1_IN2              SCK

#define PIN_M2_EN               5
#define PIN_M2_IN1              8
#define PIN_M2_IN2              MISO

//
//Lap Sensor Settings
//
#define INTERRUPT_PIN           0
#define CROSS_COUNTER           6      

//
// Servos for Ackerman
//
#define PIN_ACKERMAN_LEFT        13
#define PIN_ACKERMAN_RIGHT       9

//
// VBat Reader (battery status)
//
#define VBAT_ALARMED           7.10
#define VBAT_WARNED            7.40

#define PIN_VBAT                A4
#define VBAT_VOLTAGE(adc)       (adc - 534) * (8.23 - 6.47) / (662-534) + 6.47
// ((adc - 40.3) / 88.3)


//
// Bluetooth Configs (Type here)
//
#define Bluetooth               Serial


#endif

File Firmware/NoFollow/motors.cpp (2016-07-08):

#include <Servo.h>
#include <EEPROM.h>
#include <Arduino.h>

#include "_config.h"
#include "_types.h"

#include "robot.h"
#include "motors.h"

float Motors::avgSpeed = 0;
int8_t Motors::steeringPhase = 0;
int8_t Motors::steeringConverge = 0;

Servo ackermanLeft;
Servo ackermanRight;

// Initialize pins
void Motors::init(){
	// LOG("Motors::init\n");

  // Load Steering settigs from EEPROM
  Motors::steeringPhase = EEPROM.read(EEPROM_STEER_PHASE);
  Motors::steeringConverge = EEPROM.read(EEPROM_STEER_CONVERGE);

  // ackermanLeft.attach(PIN_ACKERMAN_LEFT);
  // ackermanLeft.write(90);

  // ackermanRight.attach(PIN_ACKERMAN_RIGHT);
  // ackermanRight.write(90);

	pinMode(PIN_M1_EN, OUTPUT);
	pinMode(PIN_M2_EN, OUTPUT);

	pinMode(PIN_M1_IN1, OUTPUT);
	pinMode(PIN_M2_IN1, OUTPUT);

	pinMode(PIN_M1_IN2, OUTPUT);
	pinMode(PIN_M2_IN2, OUTPUT);

  Motors::setPower(0, 0);
  Motors::setSteering(0, true);
}

// Sets the steering for the wheels
#define SERVO_MAX       150
void Motors::setSteering(float steer, bool activate){
  static bool activated;

  if(activate && !activated){
    ackermanLeft.attach(PIN_ACKERMAN_LEFT);
    ackermanRight.attach(PIN_ACKERMAN_RIGHT);
    activated = true;
  }else if(!activate && activated){
    ackermanLeft.detach();
    ackermanRight.detach();
    activated = false;
  }
  // Calculate Limited Steering (Goes from -100 to 100)
  steer = -min(max(steer, -100.0), 100.0);

  // Applies Ackerman
  float left  = (steer > 0 ?  steer : 0) * 0.3;
  float right = (steer < 0 ? -steer : 0) * 0.3;

  left  = (  left + steer) * (SERVO_MAX / 200.0) + 90;
  right = (-right + steer) * (SERVO_MAX / 200.0) + 90;

  // Applies Phase
  left  += Motors::steeringPhase;
  right += Motors::steeringPhase;

  // Applies Converge
  left  += Motors::steeringConverge;
  right -= Motors::steeringConverge;

  // Max/Min
  left  = min(max( left, 180 - SERVO_MAX), SERVO_MAX);
  right = min(max(right, 180 - SERVO_MAX), SERVO_MAX);

  ackermanLeft.write(left);
  ackermanRight.write(right);
}

// Set power of both DC motors
void Motors::setPower(float m1, float m2){

	// Motors::avgSpeed = (m1 + m2) / 2.0;

	// Limit Powers
	m1 = min(max(m1, -100), 100);
	m2 = min(max(m2, -100), 100);

	// Map powers
	int powerOutA = m1 * (MOTOR_ABS_MAX * (1/100.0));
	int powerOutB = m2 * (MOTOR_ABS_MAX * (1/100.0));

	// Set power
	analogWrite(PIN_M1_EN, abs(powerOutA));
	analogWrite(PIN_M2_EN, abs(powerOutB));

	// Set Directions
	digitalWrite(PIN_M1_IN1, powerOutA >  0 ? HIGH : LOW);
	digitalWrite(PIN_M1_IN2, powerOutA >= 0 ? LOW : HIGH);

	digitalWrite(PIN_M2_IN1, powerOutB >  0 ? HIGH : LOW);
	digitalWrite(PIN_M2_IN2, powerOutB >= 0 ? LOW : HIGH);

}

void Motors::stop(){
	// Stop motor 1
	digitalWrite(PIN_M1_EN, LOW);
	digitalWrite(PIN_M1_IN1, LOW);
  digitalWrite(PIN_M1_IN2, LOW);

  // Stop motor 2
  digitalWrite(PIN_M2_EN, LOW);
  digitalWrite(PIN_M2_IN1, LOW);
  digitalWrite(PIN_M2_IN2, LOW);
}

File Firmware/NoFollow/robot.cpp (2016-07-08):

#include <Arduino.h>
#include <Thread.h>

#include "_config.h"
#include "_types.h"

#include "imu.h"
#include "robot.h"
#include "motors.h"

//
// Main Thread Controller
//
ThreadController system;

//
// Thread: Beeper
//
void threadBeeper_run();
Thread threadBeeper(threadBeeper_run, 5);

//
// Thread: Battery Checker
//
//void threadBatteryChecker_run();
//Thread threadBatteryChecker(threadBatteryChecker_run, 3000);

//
// Thread: LED thread
//
//void threadWatchdog_run();
//Thread threadWatchdog(threadWatchdog_run, 500);

//
// Thread: IMU
//
void imu_run();
// IMUThread imuSensor;


// ====================================
//           INITIALIZERS
// ====================================
void Robot::init(){

  // Initialize Serial and Wait to be ok
  Serial.begin(SERIAL_SPEED);
  // while(!Serial && millis() < 2000);
  delay(50);

  // Debug init
  LOG("Robot::init\n");

  // Log current version
  LOG("\n===== "); LOG(PROJECT_NAME); LOG(" =====\n");
  LOG(PROJECT_VERSION); LOG("\n\n");

  // Configure I2C
  Wire.begin();
  TWBR = ((16000000L / 400000L) - 16) / 2;

  // Configure LED
  // DDRE |= (1<<2);

  // Configure Buzzer
  pinMode(PIN_BUZZER, OUTPUT);

  // Configure Battery meter
  pinMode(PIN_VBAT, INPUT);

  // Setup Beeper Thread
  Robot::setBeep(BEEP_NONE);

  // Initialize IMU
  // imuSensor = new IMUThread();
  // imuSensor.init();
  // imuSensor.setInterval(9);
  pinMode(1, INPUT);

  // Add threads to system
  // system.add(&imuSensor);
  //system.add(&threadBeeper);
  //system.add(&threadWatchdog);
  //system.add(&threadBatteryChecker);
};


// ====================================
//            ROBOT STATE
// ====================================
RobotState Robot::state = IDDLE;

void Robot::setState(RobotState _state){
  state = _state;

  if(state == IDDLE)
    Motors::stop();
};


// ====================================
//       BEEP and Voltage states
// ====================================
float Robot::vbat = 0;
int Robot::beepTimes = 2;
int Robot::beepInterval = 50;
BeepState Robot::beepState = BEEP_NONE;

void Robot::setBeep(BeepState state){
  // Skip if already in that state
  if(Robot::beepState == state)
    return;

  Robot::beepState = state;
  threadBeeper.enabled = true;

  LOG("Beep State: "); LOG(state); LOG("\n");
}

void Robot::doBeep(int _times, int interval){
  Robot::beepTimes = _times;
  Robot::beepInterval = interval;

  // Make sure Thread will run
  threadBeeper.enabled = true;

  LOG("Beep times: "); LOG(_times); LOG("\n");
}

void threadBeeper_run(){
  static bool isBeeping = false;
  static bool lastIsBeeping = false;

  // if(Robot::alarm != NONE){
    // High Priority to alarms
    // isBeeping = !isBeeping;
    // threadBeeper.setInterval(isBeeping ? 20 : 80);
  // }else
  if(Robot::beepTimes > 0){
    // Decrease beeps at each beep
    if(!isBeeping)
      Robot::beepTimes--;

    isBeeping = !isBeeping;

    threadBeeper.setInterval(isBeeping ? 30 : Robot::beepInterval);
  }else if(Robot::beepState == BEEP_NONE){
    isBeeping = false;
    threadBeeper.enabled = false;
    threadBeeper.setInterval(0);
  }else if(Robot::beepState == WARN){
    isBeeping = !isBeeping;

    threadBeeper.setInterval(isBeeping ? 30 : 1000);
  }else if(Robot::beepState == ALARM){
    isBeeping = !isBeeping;

    threadBeeper.setInterval(isBeeping ? 30 : 200);
  }

  if(lastIsBeeping != isBeeping){
    digitalWrite(PIN_BUZZER, isBeeping);
    lastIsBeeping = isBeeping;
  }
}


// ====================================
//           BATTERY CHECKER
// ====================================
//
// Checks battery voltage
//
void threadBatteryChecker_run(){
  static int alerts = 0;

  long analogVal = analogRead(PIN_VBAT);
  Robot::vbat = VBAT_VOLTAGE(analogVal);
  // LOG("VBAT: "); LOG(Robot::vbat); LOG(" ["); LOG(analogVal); LOG("]\n");

  if(Robot::vbat < VBAT_ALARMED){
    if(++alerts > 3){
      Robot::setBeep(ALARM);
    }
  }else if(Robot::vbat < VBAT_WARNED){
    if(alerts <= 0)
      Robot::setBeep(WARN);
  }else{
    // Reset filter
    alerts = 0;
    Robot::setBeep(BEEP_NONE);
  }
}


// ====================================
//        WATCHDOG/LED Thread
// ====================================
//
// Watches role robot and checks for activity. Also, toggles led
//
void threadWatchdog_run(){
  static bool ledState = false;

  // Toggle state
  ledState = !ledState;

  // Check for ALARM
  // if(Robot::alarm != NONE)
  // ledState = true;

  // Set led power to ledState state
  // ledState ? (PORTE |=  (1<<2)) : (PORTE &= ~(1<<2));

  // Set timeout acordingly to Robot's state
  //threadWatchdog.setInterval(Robot::state == IDDLE ? 500 : 100);
}


// ====================================
//         ATTITUDE/ORIENTATION
// ====================================
Quaternion Robot::q = Quaternion();
VectorFloat Robot::gravity = VectorFloat();
float Robot::ypr[3] = {0,0,0};

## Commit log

2016-03-18 Added the motors.cpp code
    Added motor 3 in config
2016-03-19 Removed the Servo implementation from Motors (It will be implemented separately)
2016-03-19 Added the pid.cpp code
    That is the version v0.1 of the PID controller
2016-04-09 //That is the version v0.1 of the IMU sensor
    //This class will contain all commands to use IMU sensor in the robot
2016-04-09 This class will contain all comands to use IMU sensor in the robot
2016-07-06 Fixed Stick Values, sizeof array in interface
    [_config.h, interface.cpp]
2016-07-06 Define Voltage function
2016-07-06 cleanup. implement line Reader and servos
2016-07-06 Associated Sensor min and max to EEPROM Address //TODO: Add Adresses of sensor min and max to _config
2016-07-06 Implemented the Encoder
2016-07-06 Changed SensorTeste to detect position. Corrected declaration type in lineReader
    [SensorsTeste.ino, lineReader.cpp]
2016-07-06 Updated SensorsTeste
2016-08-02 Eletronic upload
    [Communication.SchDoc, Core.SchDoc, Interface.SchDoc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]
2016-08-13 Eletronic update
    [Communication.SchDoc, Core.SchDoc, Interface.SchDoc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]
2016-08-27 Mechanics STL files added
    [Allen_M2x10.stl, Allen_M3x10.stl, Allen_M3x18.stl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]
